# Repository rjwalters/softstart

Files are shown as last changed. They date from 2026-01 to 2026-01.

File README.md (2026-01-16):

# Generator Soft-Start

Help small portable generators (Honda EU1000i) start window air conditioners by supplementing current during motor startup.

## The Problem

A 1000W generator can run an 8000 BTU window AC (~720W) once it's running, but the compressor's startup surge (5-7× running current for 300-500ms) overwhelms the generator, causing it to bog down or trip.

## The Solution

A supercapacitor bank that:
1. Charges from the AC line during normal operation
2. Detects motor startup (current surge)
3. Injects supplemental current synchronized to the AC waveform
4. Shuts off after the motor reaches speed

## Design

```
GENERATOR ──┬──────────────────────────────────────┬── LOAD (AC Unit)
            │                                      │
            │   ┌────────────────────────────┐     │
            │   │      SUPERCAP BANK         │     │
            │   │   30 × 12F 2.7V = 81V      │     │
            └───┤                            ├─────┘
                │   Charging    Discharge    │
                │   Circuit     MOSFET       │
                │       ↑          ↑         │
                │       └────┬─────┘         │
                │            │               │
                │      ┌─────┴─────┐         │
                │      │  STM32    │         │
                │      │  MCU      │         │
                │      └───────────┘         │
                └────────────────────────────┘
                        × 2 banks
                  (positive & negative half-cycles)
```

## Specifications

| Parameter | Value |
|---|---|
| Supercapacitors | 60 × Tecate 12F 2.7V |
| Bank voltage | 81V (30 series per bank) |
| AC coverage | 32% of waveform |
| Energy delivery | ~110J in 200ms |
| Effective current | ~14A RMS |
| MCU | STM32G031 |
| **Estimated BOM** | **~$85** |

## Key Components

| Component | Part Number | Qty | Unit Cost |
|---|---|-----|---|
| Supercapacitor | Tecate TPLH-2R7/12WR10X30 | 60 | $0.91 |
| MCU | STM32G031F6P6 | 1 | $1.50 |
| MOSFET | IRFB4110 | 2 | $1.50 |
| PCB | JLCPCB 2-layer | 1 | ~$15 |

## How It Works

1. **Charging:** Supercaps charge through current-limiting resistors when AC voltage is in safe range
2. **Detection:** MCU monitors load current; spike indicates motor starting
3. **Injection:** When V_ac < 81V (near zero-crossing), MOSFET connects supercap bank
4. **PWM Control:** MCU shapes injection current to approximate sinusoid
5. **Timeout:** Assist limited to 500ms to prevent overheating

### Phase Alignment Advantage

Motor current *lags* voltage by ~70° due to inductance. This means peak current occurs near voltage zero-crossing—exactly where our injection window is. The 32% coverage captures the most critical part of the cycle.

## Project Structure

```
softstart/
├── README.md                    # This file
├── hardware/
│   ├── design_spec.md           # Detailed design specification
│   └── kicad/
│       ├── softstart.kicad_pro  # KiCad project
│       └── softstart.kicad_dru  # JLCPCB design rules
├── src/                         # Analysis scripts
├── docs/                        # Design evolution & analysis
│   ├── design_evolution.md      # How we got here
│   └── *.png                    # Analysis plots
├── requirements.txt
└── pyproject.toml
```

## Status

- [x] Design analysis complete
- [x] Component selection finalized
- [x] KiCad project initialized
- [ ] Schematic capture
- [ ] PCB layout
- [ ] Firmware development
- [ ] Prototype build
- [ ] Testing

## Safety

**This device operates at mains voltage (120VAC) and stores significant energy (81V, ~1300J). It can cause injury or death if mishandled.**

- Always discharge supercaps before servicing
- Use proper enclosure
- Include appropriate fusing
- For experimental/educational use only

## Documentation

- [Project Specification](hardware/kicad/project.kct) - Complete technical specification (kicad-tools format)
- [Design Evolution](docs/design_evolution.md) - How we explored different approaches

## License

MIT

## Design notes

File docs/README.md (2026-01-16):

# Design Documentation

This folder contains the design evolution and analysis work that led to the final supercap-only design.

## Design Evolution

See [design_evolution.md](design_evolution.md) for the complete exploration of:
- Multi-tier LiPo battery approaches (rejected)
- Hybrid supercap + electrolytic stacking (explored, rejected for complexity)
- Supercap-only with PWM (selected)

## Analysis Scripts

The `/src` folder contains Python scripts used to analyze different configurations:

| Script | Purpose |
|---|---|
| `analyze_supercap_configs.py` | Supercap-only power delivery analysis |
| `analyze_hybrid_stacking.py` | Hybrid supercap + electrolytic concept |
| `analyze_motor_startup.py` | Motor startup current requirements |
| `analyze_phase_coverage.py` | Phase alignment with inductive loads |
| `analyze_12f_design.py` | Final 12F supercap design analysis |
| `analyze_budget_design.py` | Budget constraint optimization |
| `analyze_sourcing.py` | Component sourcing options |
| `comprehensive_analysis.py` | Combined capability assessment |

## Analysis Plots

| Plot | Description |
|---|---|
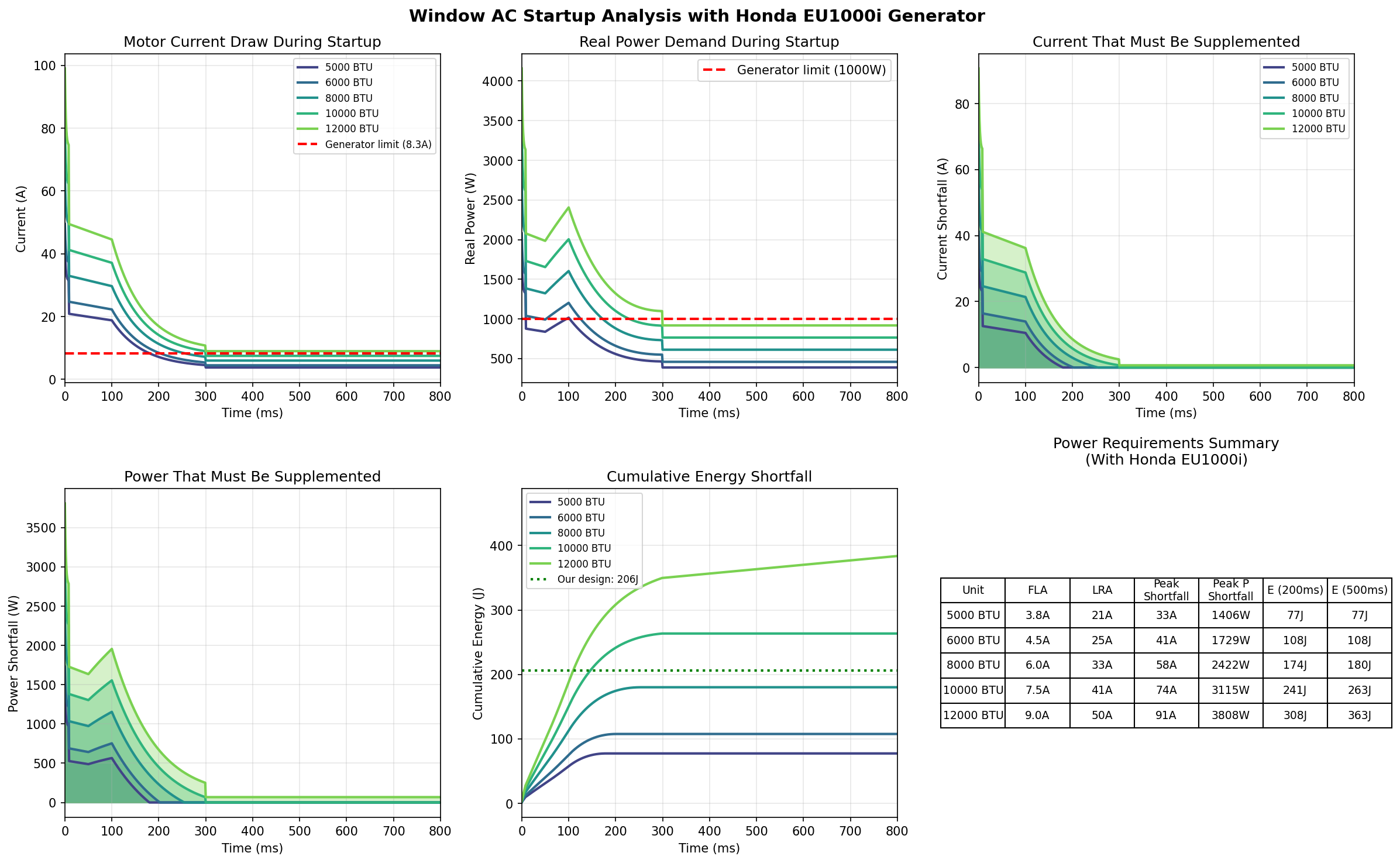
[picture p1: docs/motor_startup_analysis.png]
Motor Startup
|  | Current requirements for different AC unit sizes |
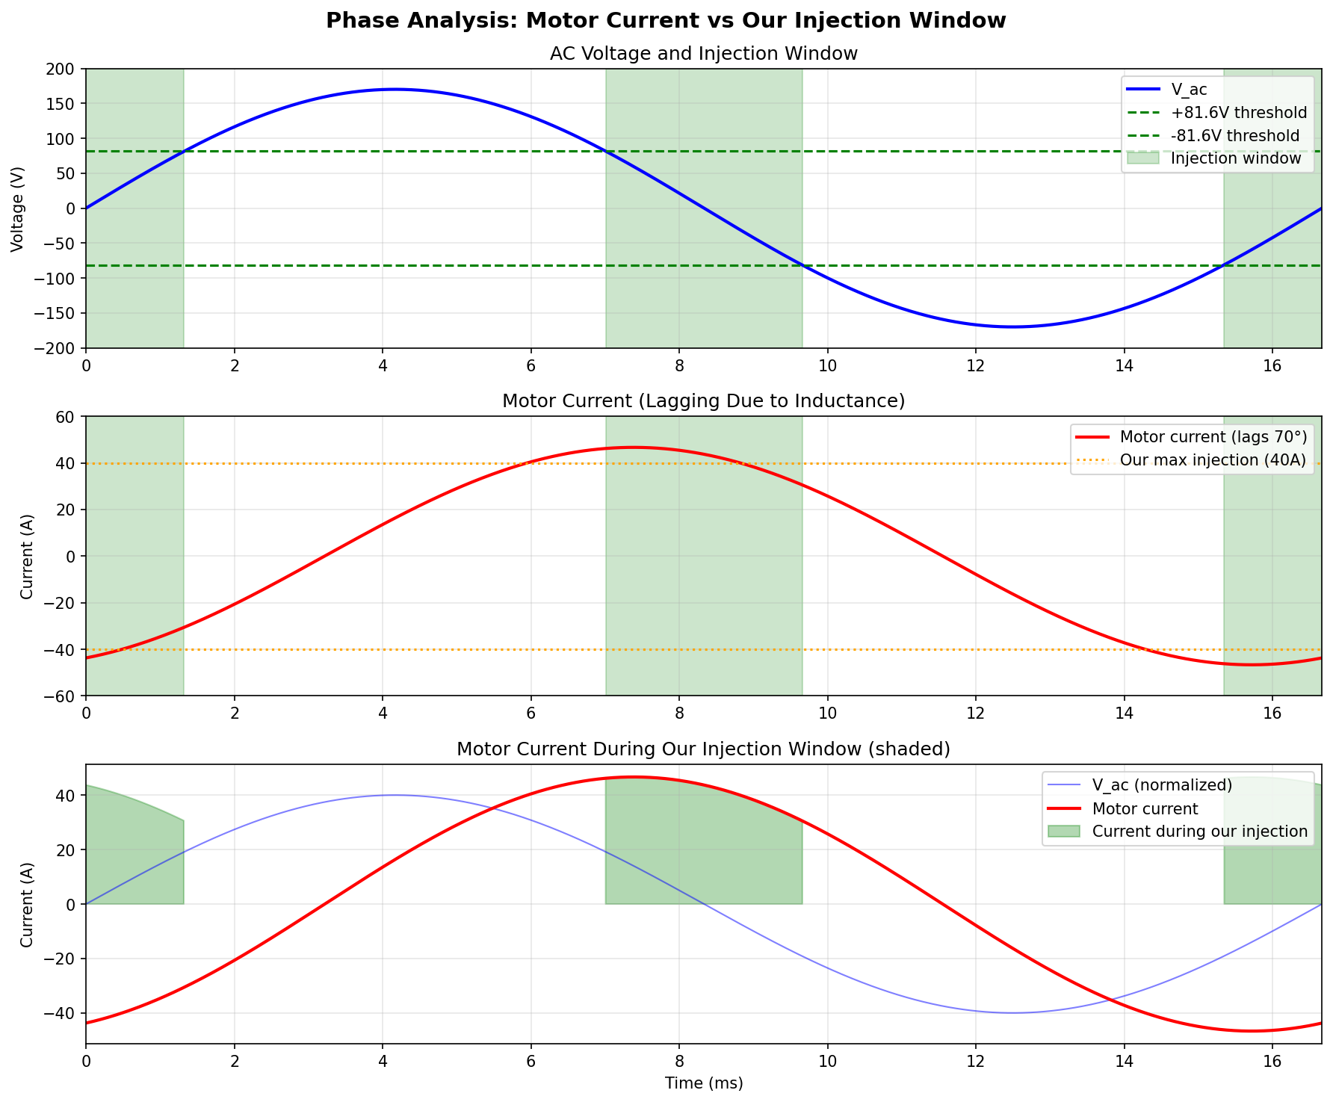
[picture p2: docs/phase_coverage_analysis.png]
Phase Coverage
|  | How injection aligns with motor current |
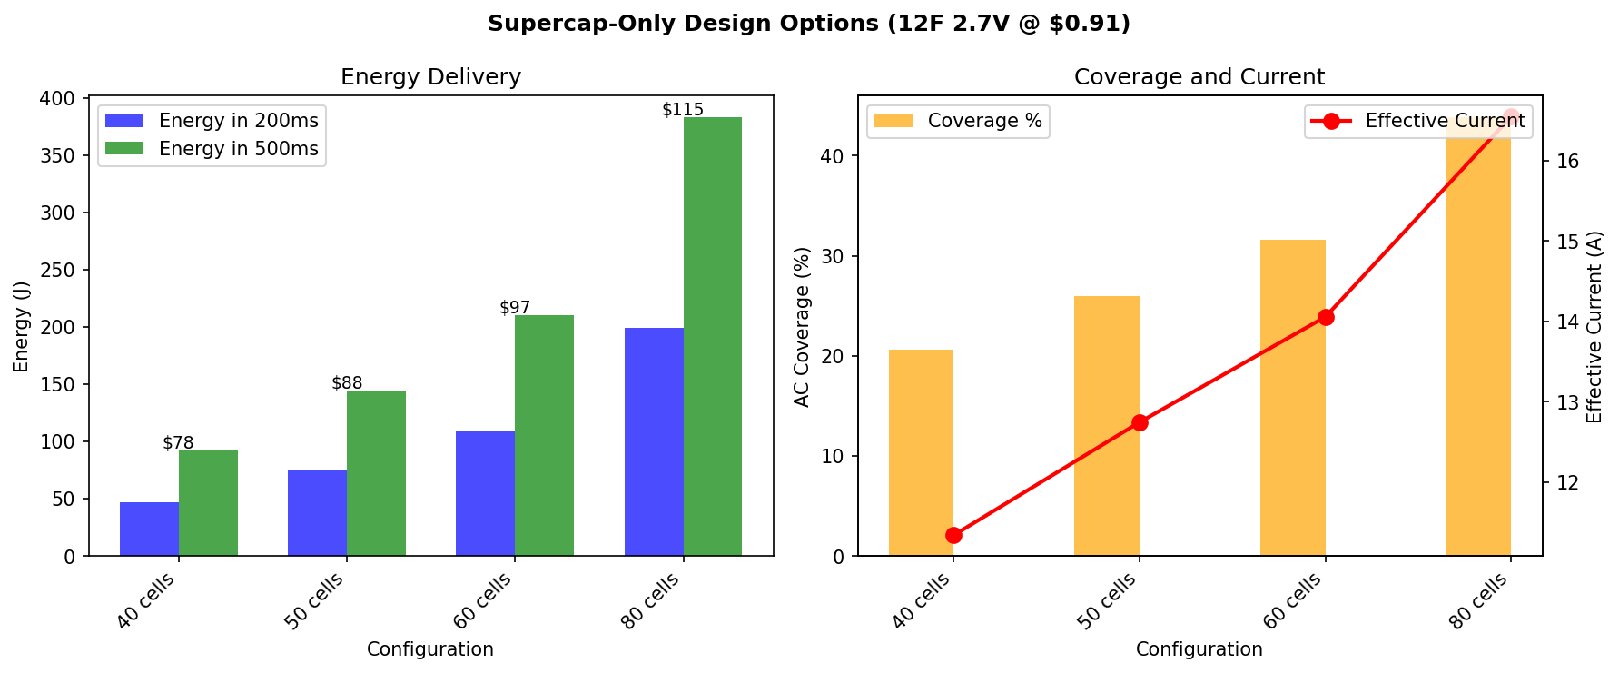
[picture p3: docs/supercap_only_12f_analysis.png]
Supercap Only
|  | Final 12F design options |
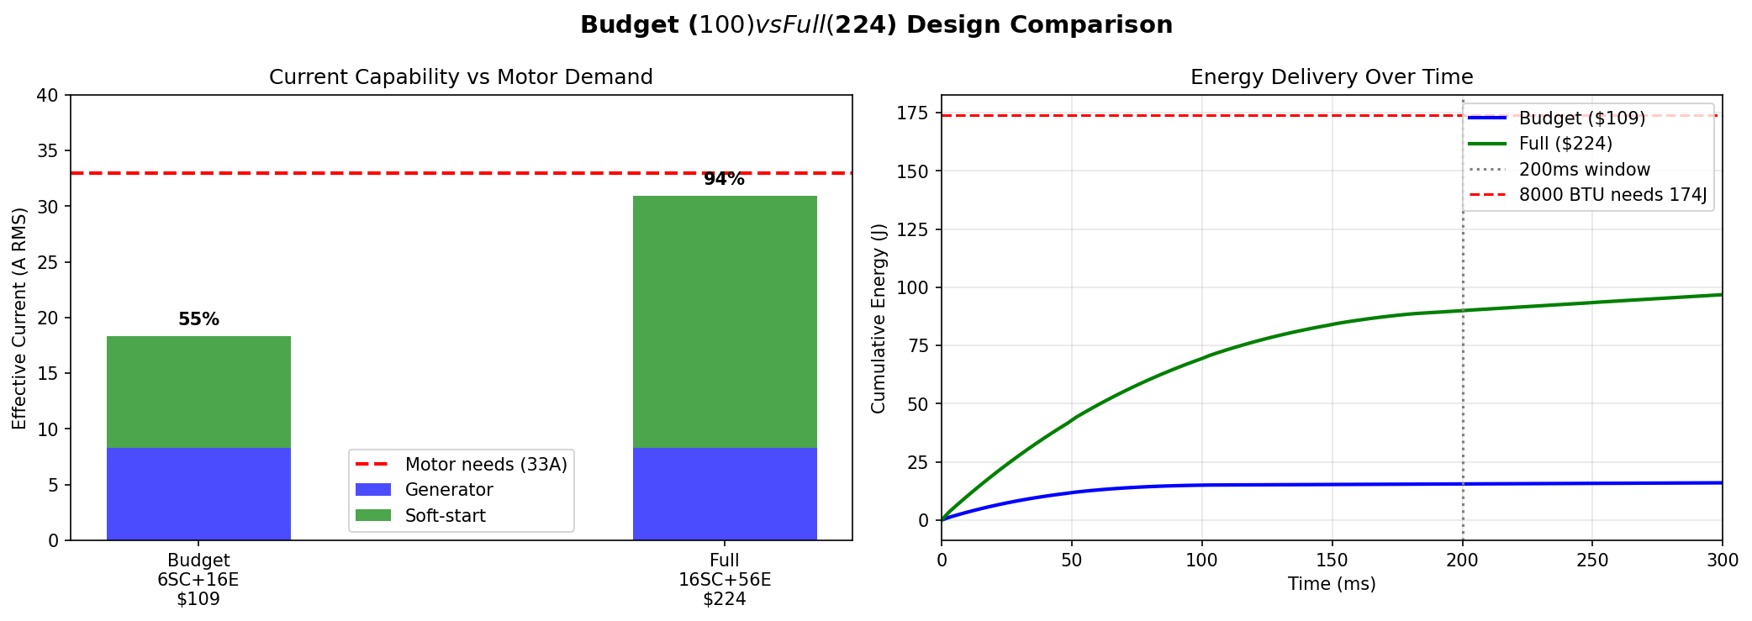
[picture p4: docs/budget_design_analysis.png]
Budget Analysis
|  | Cost vs performance trade-offs |

## Key Findings

### Motor Startup Requirements

| AC Unit | Energy Needed (200ms) | Can Start with 60-cell design? |
|---|---|---|
| 5000 BTU | ~77J | ✓ High confidence |
| 6000 BTU | ~108J | ✓ High confidence |
| 8000 BTU | ~174J | ✓ Medium confidence |
| 10000 BTU | ~241J | ? Marginal |

### Phase Alignment Advantage

Motor current lags voltage by ~70° at locked rotor (power factor ≈ 0.35). This means:
- Peak motor current occurs near voltage zero-crossing
- Our injection window (|V_ac| < 81V) includes zero-crossing
- We inject maximum current exactly when motor needs it most
- The 32% coverage captures the *critical* 32% of the AC cycle

### Why Supercap-Only Won

| Factor | Hybrid | Supercap-Only |
|---|---|---|
| Cost | $140-224 | **$85** |
| Complexity | High (8+ switches) | **Low (2 switches)** |
| Control | MCU required | Simple analog possible |
| Failure modes | Many | **Few** |
| Energy/200ms | 206J | 110J |

The hybrid delivers more energy, but the supercap-only design delivers similar *power* during the critical window at half the cost and complexity.

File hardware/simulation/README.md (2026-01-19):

# Softstart Power Supply Simulations

SPICE simulations for validating MCU power supply stability under various operating conditions.

## Overview

The softstart board uses a supercapacitor-based power assist system. The MCU power supply chain is:

```
AC Input → Bridge Rectifier (D5) → C8 (1000µF) → LM7812 → AMS1117-3.3 → STM32
```

These simulations verify that the MCU supply remains stable during:
1. **Startup** - when supercaps are discharged and drawing charging current
2. **Droop events** - when generator voltage sags and supercaps discharge
3. **Brown-out conditions** - finding minimum operating voltage

## Prerequisites

Install ngspice:

```bash
# macOS
brew install ngspice

# Ubuntu/Debian
sudo apt-get install ngspice

# Windows
# Download from http://ngspice.sourceforge.net/
```

## Running Simulations

### Run All Simulations
```bash
./run_simulations.sh all
```

### Run Individual Simulations
```bash
./run_simulations.sh startup    # Startup transient
./run_simulations.sh droop      # Droop event
./run_simulations.sh brownout   # Brown-out threshold
```

### Interactive Mode
For debugging or exploring waveforms:
```bash
./run_simulations.sh interactive startup_transient.cir
```

In ngspice interactive mode:
```
ngspice> run
ngspice> plot v(rail_3v3) v(rail_12v)
ngspice> meas tran v_min MIN v(rail_3v3)
```

## Simulation Descriptions

### 1. Startup Transient (`startup_transient.cir`)

Simulates power-on with fully discharged supercaps (worst case).

**What it tests:**
- Rectified voltage sag due to supercap charging current
- LM7812 behavior during input voltage dips
- Time to stable 3.3V rail
- MCU brown-out reset risk

**Key parameters:**
- Generator: 120V RMS, 60Hz, 2Ω internal impedance
- Supercaps: 0V initial (worst case)
- Precharge: 100Ω/220Ω resistors

**Pass criteria:**
- 3.3V rail never drops below 2.0V (BOR threshold)
- 12V rail stays above 10V

### 2. Droop Event (`droop_event.cir`)

Simulates generator voltage droop that triggers supercap assist.

**What it tests:**
- MCU supply during 25% voltage droop
- Transition behavior when supercaps start discharging
- Recovery when voltage returns to normal

**Key parameters:**
- Normal: 120V RMS
- Droop: 90V RMS (25% reduction)
- Droop duration: 200ms
- Supercaps: 60V initial (charged)

**Pass criteria:**
- No MCU reset during droop event
- 3.3V rail stays above 3.0V

### 3. Brown-out Threshold (`brownout_threshold.cir`)

Determines minimum AC input voltage for stable MCU operation.

**What it tests:**
- Slow ramp from 120V to 40V RMS
- Find exact voltage where each rail loses regulation
- Calculate safety margins

**Key measurements:**
- AC voltage where 12V rail < 11V (dropout)
- AC voltage where 3.3V rail < 3.0V (warning)
- AC voltage where 3.3V rail < 2.0V (BOR)

## Component Models

Models are in `lib/components.lib`:

| Model | Description |
|---|---|
| `LM7812` | 12V linear regulator with dropout behavior |
| `AMS1117` | 3.3V LDO with 1.1V dropout |
| `SUPERCAP_BANK_30S` | 30-series supercap bank (0.4F, 0.9Ω ESR) |
| `BRIDGE_RECT` | MB6S equivalent bridge rectifier |
| `GENERATOR` | AC source with internal impedance |
| `GENERATOR_DROOP` | AC source with controllable voltage droop |
| `STM32_LOAD` | MCU current draw and BOR detection |

## Results

Results are saved to `results/`:
- `.csv` files with waveform data
- `.log` files with measurement outputs

## Interpreting Results

### Good Results
```
PASS: 3.3V rail stayed above brownout threshold
      Minimum was: 3.15 V
PASS: No MCU reset during droop
```

### Concerning Results
```
WARNING: 3.3V rail dropped below 3.0V during droop
         Minimum: 2.85 V
```

### Failing Results
```
FAIL: 3.3V rail dropped below brownout threshold (2.0V)
      Minimum was: 1.8 V
FAIL: MCU reset during droop event!
```

## Potential Mitigations

If simulations show MCU supply instability:

1. **Increase C8** - More bulk capacitance on LM7812 input
2. **Add capacitance on 3.3V** - More local bypass (C1/C2)
3. **Supervisor IC** - Add voltage monitor with reset hold-off
4. **Separate supply** - Dedicated small transformer for MCU
5. **Pre-regulator** - Add switching pre-reg before LM7812
6. **Delay MCU startup** - Wait for supercaps to charge

## Files

```
simulation/
├── README.md                 # This file
├── run_simulations.sh        # Run script
├── lib/
│   └── components.lib        # SPICE component models
├── startup_transient.cir     # Startup test bench
├── droop_event.cir           # Droop test bench
├── brownout_threshold.cir    # Brown-out test bench
└── results/                  # Output directory
```

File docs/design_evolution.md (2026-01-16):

# Generator Power Assist (Soft Start)

## Problem Statement

Small portable generators (like the Honda EU1000i, ~1000W) struggle with inductive startup loads. When an air conditioner or refrigerator compressor starts, it draws 3-6x its running current for 1-3 seconds. This startup surge can exceed the generator's capacity, causing it to bog down or trip.

**Goal:** Supplement the generator with ~500-800W of additional power for 2-3 seconds during motor startup. The generator still provides most of the power - we just help it over the hump.

## Design Evolution

Through analysis and simulation, we explored several approaches:

1. **Multi-tier LiPo batteries** - Different voltage tiers (2S, 4S, 8S) for different parts of the AC waveform. Rejected due to BMS complexity and cycle life concerns.

2. **Supercap-only with PWM** - Simple and robust, but limited AC coverage means lower effective power delivery.

3. **Hybrid supercap + electrolytic stacking** - Best cost/performance ratio. Electrolytics provide voltage boost, supercaps provide energy storage.

## Recommended Design: Hybrid Stacking

### Core Concept

**Charge separately, discharge in series:**

```
CHARGING (separate windows):              DISCHARGING (series):

AC passes through 24V:                         Load
  → Supercaps charge to 24V                      ↑
                                           ┌─────┴─────┐
AC passes through 60V:                     │  Supercap │ 24V
  → Electrolytics charge to 60V            │   Bank    │
                                           ├───────────┤
                                           │Electrolytic│ 60V
                                           │   Bank    │
                                           └─────┬─────┘
                                              Neutral

                                    Stacked voltage: 84V
                                    Coverage: 33% of AC cycle
```

### Why Hybrid Stacking Works

| Component | Strength | Role in Hybrid |
|---|---|---|
| Supercaps | High energy density, high current | Energy storage |
| Electrolytics | High voltage rating, cheap | Voltage boost |

**Key insight:** Electrolytics are cheap per volt, supercaps are cheap per joule. Combining them optimizes both.

### Configuration Analysis

We analyzed configurations across 12-20 supercaps × 40-64 electrolytics:

**Energy delivered in first 200ms (critical motor start window):**

```
        │   40E   │   44E   │   48E   │   52E   │   56E   │   60E   │
────────┼─────────┼─────────┼─────────┼─────────┼─────────┼─────────┤
  12SC  │   129J  │   142J  │   154J  │   166J  │   178J  │   180J  │
  14SC  │   140J  │   153J  │   166J  │   179J  │   192J  │   194J  │
  16SC  │   151J  │   165J  │   178J  │   192J  │   206J  │   208J  │
  18SC  │   162J  │   177J  │   191J  │   206J  │   220J  │   223J  │
  20SC  │   174J  │   190J  │   205J  │   220J  │   235J  │   238J  │
```

**Cost ($):**

```
        │   40E   │   44E   │   48E   │   52E   │   56E   │   60E   │
────────┼─────────┼─────────┼─────────┼─────────┼─────────┼─────────┤
  12SC  │  $163   │  $172   │  $181   │  $191   │  $200   │  $209   │
  14SC  │  $175   │  $184   │  $193   │  $203   │  $212   │  $221   │
  16SC  │  $187   │  $196   │  $205   │  $215   │  $224   │  $233   │
  18SC  │  $199   │  $208   │  $217   │  $227   │  $236   │  $245   │
  20SC  │  $211   │  $220   │  $229   │  $239   │  $248   │  $257   │
```

**Sweet spot: 56 electrolytics** - Provides ~197ms boost duration, just covering the critical 200ms window. More electrolytics beyond this don't help.

### Recommended Configurations

| Goal | Config | Cost | Energy | J/$ | Notes |
|---|---|---|---|-----|---|
| **Budget** | 18SC+40E | $199 | 162J | 0.81 | Good balance |
| **Best value** | 16SC+56E | $224 | 206J | 0.92 | Optimal J/$ |
| **Maximum** | 20SC+56E | $248 | 235J | 0.95 | Best efficiency |

### Primary Recommendation: 16SC + 56E

| Parameter | Value |
|---|---|
| Supercaps | 16 total (8 per bank) |
| Electrolytics | 56 total (28 per bank) |
| **Total Cost** | **$224** |
| Supercap voltage | 21.6V (8 × 2.7V) |
| Stacked voltage | 81.6V |
| AC coverage | 32% |
| Boost duration | 197ms |
| Energy in 200ms | 206J |
| Peak power | ~1,000W |

**Cost breakdown:**
- Supercaps (100F 2.7V): 16 × $6.00 = $96
- Electrolytics (4700µF 100V): 56 × $2.28 = $128

## Target Application: Window AC Units

### Motor Startup Characteristics

Window AC compressors are challenging inductive loads:

| Unit Size | Running | FLA | LRA (5.5×) | Startup Time |
|---|---|-----|---|---|
| 5000 BTU  | 450W | 3.8A | 21A | ~200ms |
| 6000 BTU  | 540W | 4.5A | 25A | ~250ms |
| 8000 BTU  | 720W | 6.0A | 33A | ~300ms |
| 10000 BTU | 900W | 7.5A | 41A | ~350ms |
| 12000 BTU | 1080W | 9.0A | 50A | ~400ms |

**Key insight:** LRA (Locked Rotor Amps) is typically 5-7× the running current and lasts 0.5-1.5 seconds.

### Startup Current Profile

```
Current
  ↑
  │    ┌──────┐
  │    │      │ LRA (Locked Rotor)
  │    │      └──────┐
  │    │              └───────┐
  │    │                      └────────── FLA (Running)
  │    │
  └────┴──────────────────────────────────────→ Time
       0    100ms  200ms  300ms  500ms

  Phase 1: Initial surge (0-8ms) - up to 20× FLA
  Phase 2: Locked rotor (8-180ms) - ~5-7× FLA
  Phase 3: Acceleration (180-500ms) - decreasing
  Phase 4: Running - FLA steady state
```

### Phase Alignment Advantage

Our design benefits from motor inductance:

- **Motor current lags voltage by ~70°** at locked rotor (PF ≈ 0.35)
- **Peak motor current occurs near voltage zero-crossing**
- **Our injection window includes zero-crossing** (|V_ac| < 81.6V)
- **We inject maximum current exactly when motor needs it most!**

```
         V_ac                    I_motor (lagging 70°)
           │                           │
    Peak → │ ╱╲                        │    ╱╲
           │╱  ╲                       │   ╱  ╲
   ────────┼────╲─────────────────────┼──╱────╲──────
           │     ╲  ╱                  │ ╱      ╲
           │      ╲╱ ← Zero crossing   │╱        ╲ ← Peak current HERE
           │                           │

Our injection window: when |V_ac| < 81.6V (shaded region around zero crossing)
Motor peak current: at zero crossing due to 70° lag

Result: 32% AC coverage captures the most critical 32%!
```

### Capability Matrix

**Honda EU1000i + Our Hybrid Boost:**

| AC Unit | Energy Needed | Our Capacity | Margin | Can Start? |
|---|---|---|---|---|
| 5000 BTU | ~77J in 200ms | 206J | +129J | ✓✓ HIGH |
| 6000 BTU | ~108J in 200ms | 206J | +98J | ✓✓ HIGH |
| **8000 BTU** | **~174J in 200ms** | **206J** | **+32J** | **✓ MEDIUM** |
| 10000 BTU | ~241J in 200ms | 206J | -35J | ? MARGINAL |
| 12000 BTU | ~308J in 200ms | 206J | -102J | ✗ NO |

### Detailed Analysis: 8000 BTU (Target Application)

**Without soft-start:**
- Motor demands 33A LRA
- Generator can supply 8.3A max
- Shortfall: 24.7A → **voltage collapses, motor stalls**

**With our soft-start:**
- Generator provides: 8.3A
- We inject: up to 40A peak (22.6A effective RMS)
- At zero-crossing: 45.9A combined vs 43.9A needed
- Current margin: +2.0A → **motor starts successfully**

### Recommendations by Unit Size

| Target Unit | Recommended Config | Cost | Confidence |
|---|---|---|---|
| 5000-6000 BTU | Budget (18SC+40E) | $199 | HIGH |
| **8000 BTU** | **Recommended (16SC+56E)** | **$224** | **MEDIUM** |
| 10000 BTU | Maximum (20SC+56E) | $248 | LOW |
| 12000+ BTU | Use EU2200i instead | - | - |

## Why Electrolytics Need Parallel Connection

Electrolytics are paralleled for two reasons:

### 1. Discharge Duration
```
Single 4700µF at 40A:
  dV/dt = 40A / 0.0047F = 8,511 V/s
  Time to discharge 60V: 7ms (way too short!)

28 × 4700µF at 40A:
  Time to discharge: 197ms ✓
```

### 2. Current Handling
```
Single 4700µF ripple current rating: ~3A
For 40A discharge: need 40A / 3A ≈ 14 caps minimum

We use 28 per bank for duration + current margin.
```

## Circuit Architecture

```
                        POSITIVE HALF-CYCLE BANK

AC Hot ────┬─────────────────────────────────────────────────┬──── Load
           │                                                 │
           │         CHARGING MODE                           │
           │    ┌────────────────────────┐                   │
           ├────┤ SW_sc_chg              │                   │
           │    │    ↓                   │                   │
           │    │ [Supercap Bank]        │                   │
           │    │   8S × 100F = 12.5F    │                   │
           │    │   @ 21.6V              │                   │
           │    └────────┬───────────────┘                   │
           │             │                                   │
           │    ┌────────┴───────────────┐                   │
           ├────┤ SW_el_chg              │                   │
           │    │    ↓                   │                   │
           │    │ [Electrolytic Bank]    │                   │
           │    │  28 × 4700µF = 0.13F   │                   │
           │    │   @ 60V                │                   │
           │    └────────────────────────┘                   │
           │                                                 │
           │         DISCHARGE MODE (SERIES)                 │
           │    ┌────────────────────────┐                   │
           │    │      [Supercap]        │                   │
           │    │         21.6V          │                   │
           │    │           +            │                   │
           │    │     [Electrolytic]     ├───[SW_discharge]──┤
           │    │         60V            │                   │
           │    │           =            │                   │
           │    │     81.6V stacked      │                   │
           │    └────────────────────────┘                   │
           │                                                 │
Neutral ───┴─────────────────────────────────────────────────┴──── Neutral

                    (Mirror for negative half-cycle bank)
```

### Operating Modes

**Charging (Normal Operation):**
1. Monitor V_ac continuously
2. When V_ac passes through ~22V: close SW_sc_chg briefly → supercaps charge
3. When V_ac passes through ~60V: close SW_el_chg briefly → electrolytics charge
4. Banks charge independently

**Discharging (Motor Start Assist):**
1. Detect motor start (current surge or voltage dip)
2. Reconfigure switches to connect banks in series
3. Close SW_discharge with PWM control when V_ac < 81.6V
4. Inject sinusoidal current synchronized to AC phase
5. After ~200ms, electrolytics depleted → falls back to supercap-only voltage

### Switching Requirements

| Switch | Voltage Rating | Current | Qty | Notes |
|---|---|---|-----|---|
| SW_sc_chg | 50V | 20A | 2 | Supercap charging |
| SW_el_chg | 100V | 10A | 2 | Electrolytic charging |
| SW_discharge | 100V | 40A | 2 | Main power path |
| SW_series | 100V | 40A | 2 | Series connection |

## Bill of Materials

| Component | Spec | Qty | Unit | Total | Notes |
|---|---|-----|---|---|---|
| Supercapacitor | 100F 2.7V | 16 | $6.00 | $96 | 8S × 2 banks |
| Electrolytic | 4700µF 100V | 56 | $2.28 | $128 | 28 × 2 banks |
| MOSFET (charge) | 100V 20A | 4 | $1.00 | $4 | |
| MOSFET (discharge) | 100V 50A | 4 | $2.00 | $8 | IRFB4110 |
| Gate driver | IR2110 | 2 | $2.00 | $4 | |
| Current shunt | 0.01Ω 5W | 2 | $1.00 | $2 | |
| Inductor | 100µH 40A | 2 | $4.00 | $8 | PWM filtering |
| MCU | STM32F103 | 1 | $4.00 | $4 | |
| Voltage sensing | Dividers + opamp | 1 | $3.00 | $3 | |
| Connectors, fuses | Various | - | - | $15 | |
| PCB | JLCPCB 2-layer | 1 | $20.00 | $20 | ~150×200mm |
| **Total** | | | | **~$292** | |

### Alternative: Budget Build (18SC + 40E)

| Component | Qty | Cost |
|---|-----|---|
| Supercapacitors | 18 | $108 |
| Electrolytics | 40 | $91 |
| Electronics | - | ~$68 |
| **Total** | | **~$267** |

Delivers 162J in 200ms vs 206J for the recommended config.

## Specifications

| Parameter | Value | Notes |
|---|---|---|
| Input/Output | 120VAC 60Hz | Pass-through |
| Max continuous | 20A | |
| Stacked voltage | 81.6V | During boost |
| AC coverage | 32% | During boost |
| Boost duration | 197ms | Then supercap-only |
| Energy (200ms) | 206J | Critical window |
| Peak power | ~1,000W | During boost |
| Recovery time | ~60s | Full recharge |

## Comparison: Hybrid vs Supercap-Only

| Metric | Supercap Only (50SC) | Hybrid (16SC+56E) |
|---|---|---|
| Cost | $300 | $224 |
| Voltage | 67.5V | 81.6V |
| Coverage | 26% | 32% |
| Energy/200ms | ~85J | 206J |
| Peak power | ~700W | ~1,000W |
| Complexity | Simple | Moderate |

**Hybrid delivers 2.4× more energy at 25% lower cost.**

## Firmware Architecture

### State Machine

```
                      ┌─────────┐
                      │  INIT   │
                      └────┬────┘
                           │
                           ▼
         ┌─────────────────────────────────┐
         │          CHARGING               │
         │  - Monitor V_ac                 │
         │  - Charge supercaps at ~22V     │
         │  - Charge electrolytics at ~60V │
         └───────────────┬─────────────────┘
                         │ Both banks charged
                         ▼
                    ┌─────────┐
         ┌─────────│  READY  │←────────────┐
         │         └────┬────┘             │
         │              │ Motor start      │ Assist complete
         │              │ detected         │
         │              ▼                  │
         │    ┌──────────────────┐         │
         │    │     BOOST        │         │
         │    │  Series discharge│─────────┤
         │    │  @ 81.6V         │         │
         │    └────────┬─────────┘         │
         │             │ Electrolytics     │
         │             │ depleted          │
         │             ▼                   │
         │    ┌──────────────────┐         │
         └───→│   SUSTAIN        │─────────┘
              │  Supercap-only   │
              │  @ 21.6V         │
              └──────────────────┘
```

### Control Loop (20kHz)

```c
void control_loop(void) {
    float v_ac = sample_voltage();
    float i_load = sample_current();

    switch (state) {
        case CHARGING:
            // Charge supercaps when V_ac ~ 22V
            if (fabs(v_ac - 22.0) < 3.0 && v_supercap < 21.0) {
                enable_supercap_charge();
            }
            // Charge electrolytics when V_ac ~ 60V
            if (fabs(v_ac - 60.0) < 5.0 && v_elec < 58.0) {
                enable_electrolytic_charge();
            }
            // Check if ready
            if (v_supercap > 20.0 && v_elec > 55.0) {
                state = READY;
            }
            break;

        case READY:
            // Detect motor start
            if (i_load > I_THRESHOLD || detect_voltage_dip()) {
                configure_series_discharge();
                state = BOOST;
                boost_timer = 0;
            }
            break;

        case BOOST:
            // PWM discharge at stacked voltage
            if (fabs(v_ac) < v_supercap + v_elec) {
                float i_target = I_MAX * fabs(sin(phase));
                pwm_current_control(i_target);
            }
            // Check if electrolytics depleted
            if (v_elec < 10.0 || boost_timer > 300) {
                configure_supercap_only();
                state = SUSTAIN;
            }
            break;

        case SUSTAIN:
            // Continue with supercap-only
            if (fabs(v_ac) < v_supercap) {
                float i_target = I_MAX * fabs(sin(phase));
                pwm_current_control(i_target);
            }
            // Return to charging when assist complete
            if (assist_complete()) {
                state = CHARGING;
            }
            break;
    }
}
```

## Safety Features

### Hardware
- Input fuse: 25A fast-blow
- MOSFETs derated 2× for voltage and current
- Thermal shutdown via NTC on heatsink
- Current limiting via series inductor

### Firmware
- Overcurrent shutdown (>50A)
- Overvoltage lockout (supercap >24V, electrolytic >65V)
- Undervoltage lockout (supercap <15V)
- Assist timeout (5 second max)
- Watchdog timer

### Operational
- No backfeed capability (current source, not voltage source)
- Fail-safe: all switches open on fault
- Soft-start charging to limit inrush

## Development Roadmap

### Phase 1: Simulation ✓
- [x] Supercap-only analysis
- [x] Hybrid stacking concept
- [x] Cost optimization matrix
- [x] Energy delivery modeling
- [x] Motor startup requirements analysis
- [x] Phase alignment analysis (inductive load)
- [x] Comprehensive capability assessment

### Phase 2: Hardware Design
- [ ] Detailed schematic (KiCad)
- [ ] PCB layout with high-current paths
- [ ] Thermal analysis
- [ ] Component sourcing

### Phase 3: Firmware
- [ ] Zero-crossing detection
- [ ] Charge management
- [ ] Series/parallel reconfiguration
- [ ] PWM current control
- [ ] Protection features

### Phase 4: Prototype & Test
- [ ] PCB fabrication
- [ ] Assembly
- [ ] Bench testing
- [ ] Motor load testing

## Files

```
softstart/
├── README.md                           # This file
├── src/
│   ├── analyze_supercap_configs.py     # Supercap-only analysis
│   ├── analyze_hybrid_stacking.py      # Hybrid concept analysis
│   ├── optimize_minimal_hybrid.py      # Cost optimization
│   ├── analyze_motor_startup.py        # Motor startup requirements
│   ├── analyze_phase_coverage.py       # Phase alignment analysis
│   └── comprehensive_analysis.py       # Full capability analysis
├── supercap_analysis.png               # Supercap-only plots
├── hybrid_stacking_analysis.png        # Hybrid comparison plots
├── minimal_hybrid_optimization.png     # Cost optimization plots
├── motor_startup_analysis.png          # Motor startup plots
├── phase_coverage_analysis.png         # Phase alignment plots
└── comprehensive_analysis.png          # Capability matrix plots
```

## References

- Honda EU1000i specifications
- Maxwell/UCAP supercapacitor datasheets (100F 2.7V)
- Nichicon/Panasonic electrolytic capacitor datasheets
- IR2110 gate driver application notes
- Motor inrush current characteristics
- [EcoFlow battery/inverter matching guide](https://www.ecoflow.com/us/blog/battery-start-air-conditioner-guide)
- [HVAC School - Start capacitor and inrush](http://www.hvacrschool.com/start-capacitor-inrush-facts-myths-part-4/)
- [Ametherm - AC motor inrush current](https://www.ametherm.com/blog/inrush-current/ac-motor-inrush/)

## License

TBD

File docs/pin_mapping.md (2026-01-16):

# STM32G031F6P6 Pin Mapping

## Signal Assignments

| Pin | Port | Function | Signal | Description |
|-----|---|---|---|---|
| 7 | PA0 | GPIO/EXTI | ZC_OUT | Zero-crossing detector input |
| 8 | PA1 | ADC_IN1 | V_AC_SENSE | AC voltage sensing |
| 9 | PA2 | ADC_IN2 | V_SC_POS | Positive supercap bank voltage |
| 10 | PA3 | ADC_IN3 | V_SC_NEG | Negative supercap bank voltage |
| 11 | PA4 | ADC_IN4 | I_SENSE | Load current sensing |
| 12 | PA5 | GPIO | CHG_EN_POS | Positive bank charge enable |
| 13 | PA6 | TIM3_CH1 | PWM_POS | Positive half-cycle discharge PWM |
| 14 | PA7 | TIM3_CH2 | PWM_NEG | Negative half-cycle discharge PWM |
| 15 | PA8 | GPIO | CHG_EN_NEG | Negative bank charge enable |
| 16 | PA11 | GPIO | LED_STATUS | Status LED output |
| 18 | PA13 | SWD | SWDIO | Debug data |
| 19 | PA14 | SWD | SWCLK | Debug clock |
| 6 | PF2 | NRST | NRST | Reset (directly to header) |

## Power Pins

| Pin | Function | Connection |
|-----|---|---|
| 4 | VDD | 3.3V rail |
| 5 | VSS | Ground |

## Unused Pins

| Pin | Port | Notes |
|-----|---|---|
| 1 | PB7/PB8 | Available for expansion |
| 2 | PB9/PC14 | Available for expansion |
| 3 | PC15 | Available for expansion |
| 17 | PA10/PA12 | Available for expansion |
| 20 | PB3-PB6 | Available for expansion |

## ADC Configuration

- ADC clock: 16 MHz (from PCLK/4)
- Resolution: 12-bit
- Sampling time: 12.5 cycles (for ~1 MHz sample rate)
- Channels: IN1, IN2, IN3, IN4 (scan mode)

## Timer Configuration

- TIM3: PWM generation for discharge MOSFETs
  - CH1 (PA6): PWM_POS
  - CH2 (PA7): PWM_NEG
  - Frequency: 20 kHz
  - Resolution: 10-bit (0-1000 duty)

## Interrupt Sources

- EXTI0 (PA0): Zero-crossing rising edge
- TIM3: PWM period interrupt for ADC trigger
- Systick: 1 kHz for state machine timing

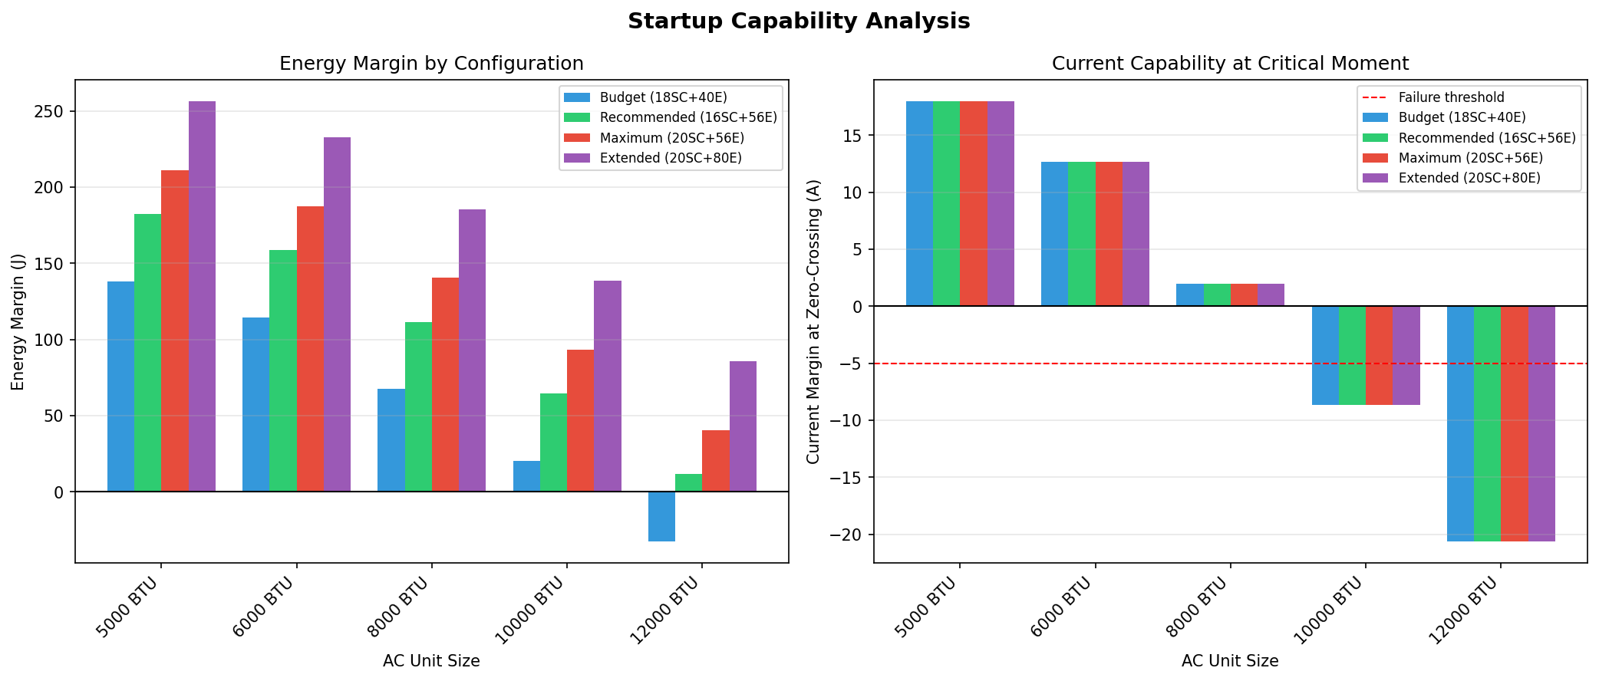
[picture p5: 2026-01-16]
docs/comprehensive_analysis.png

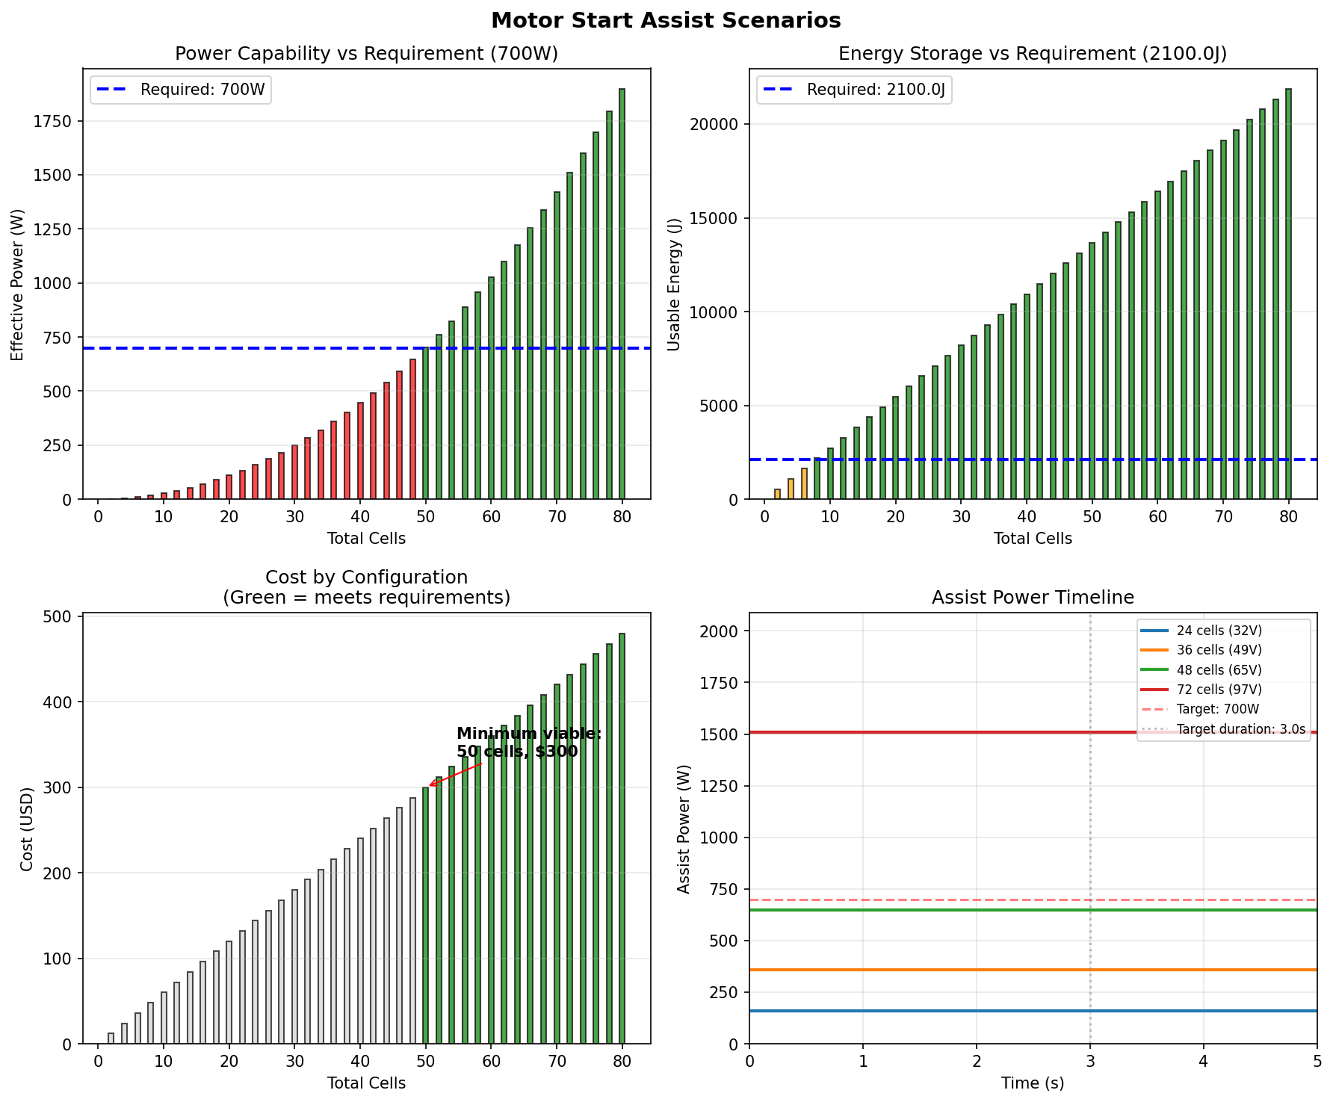
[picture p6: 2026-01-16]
docs/motor_start_scenario.png

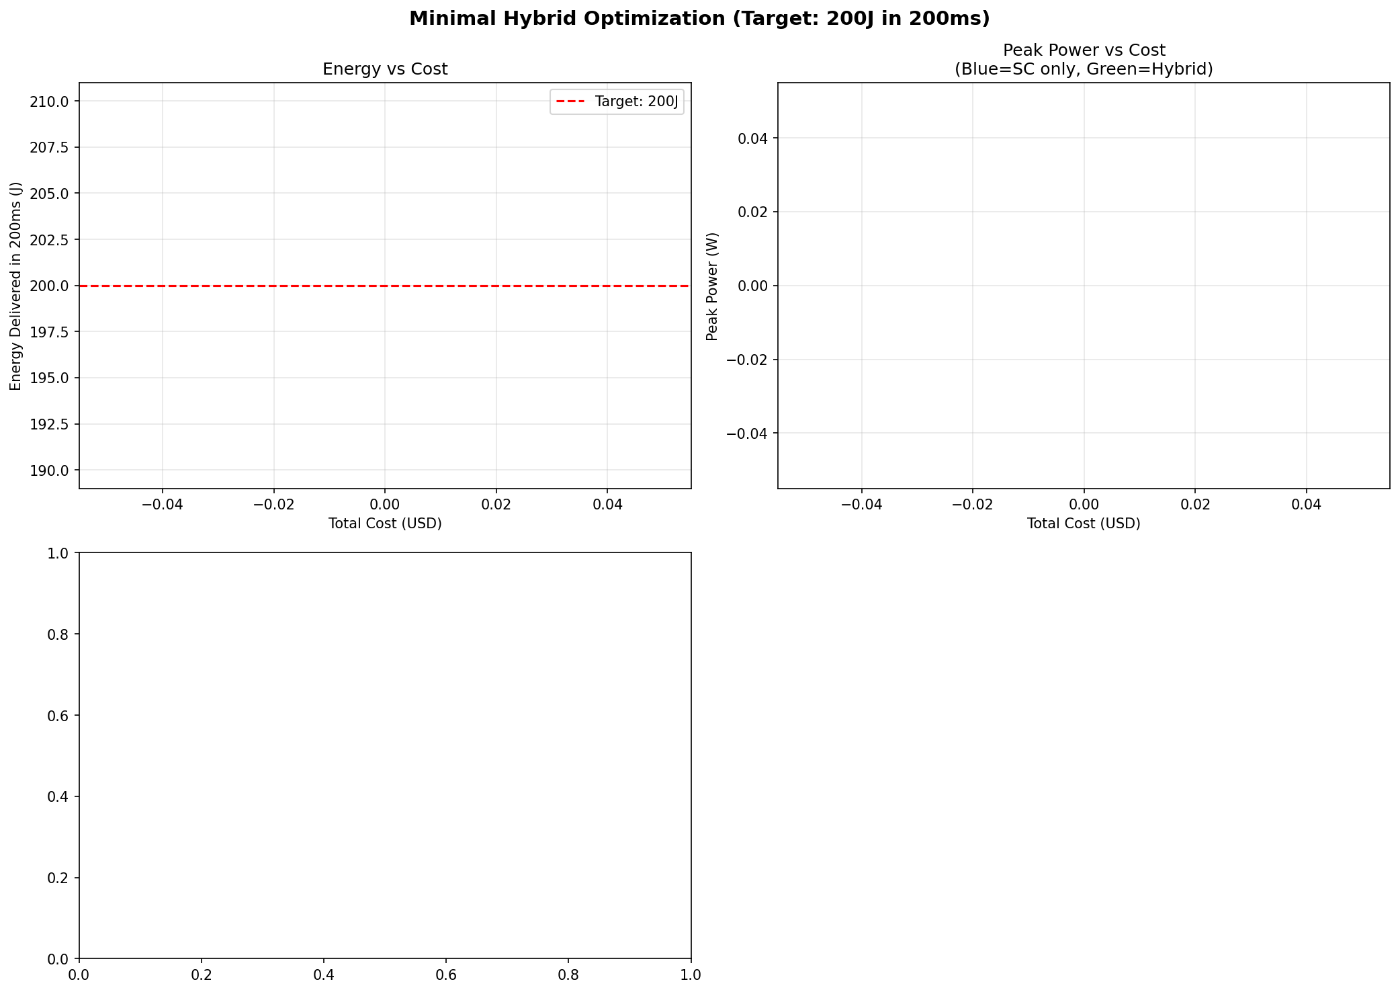
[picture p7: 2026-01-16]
docs/minimal_hybrid_optimization.png

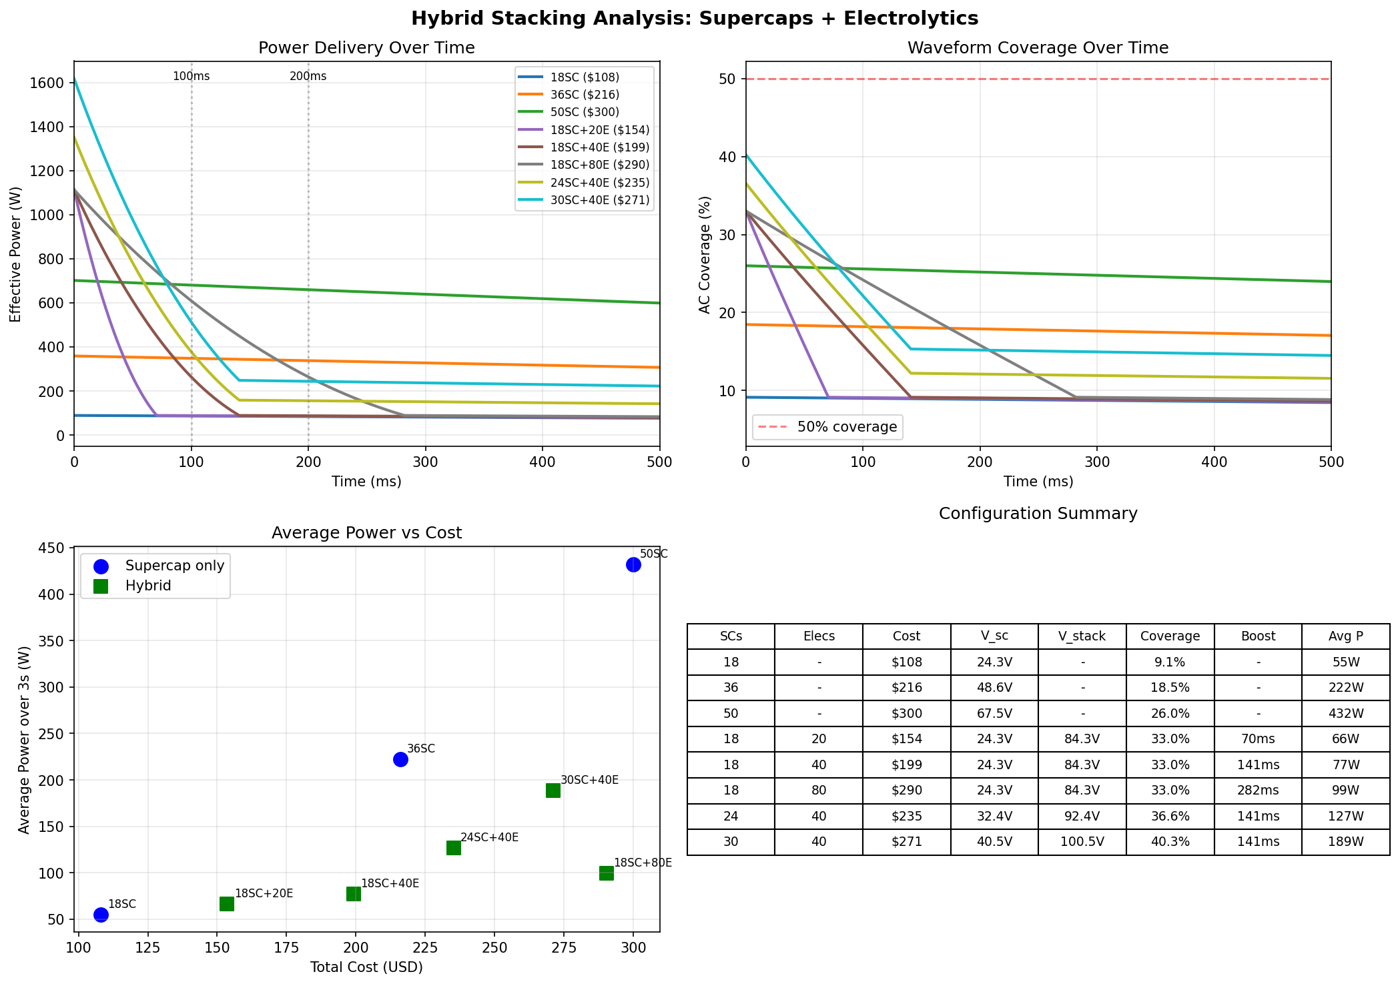
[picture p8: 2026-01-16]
docs/hybrid_stacking_analysis.png

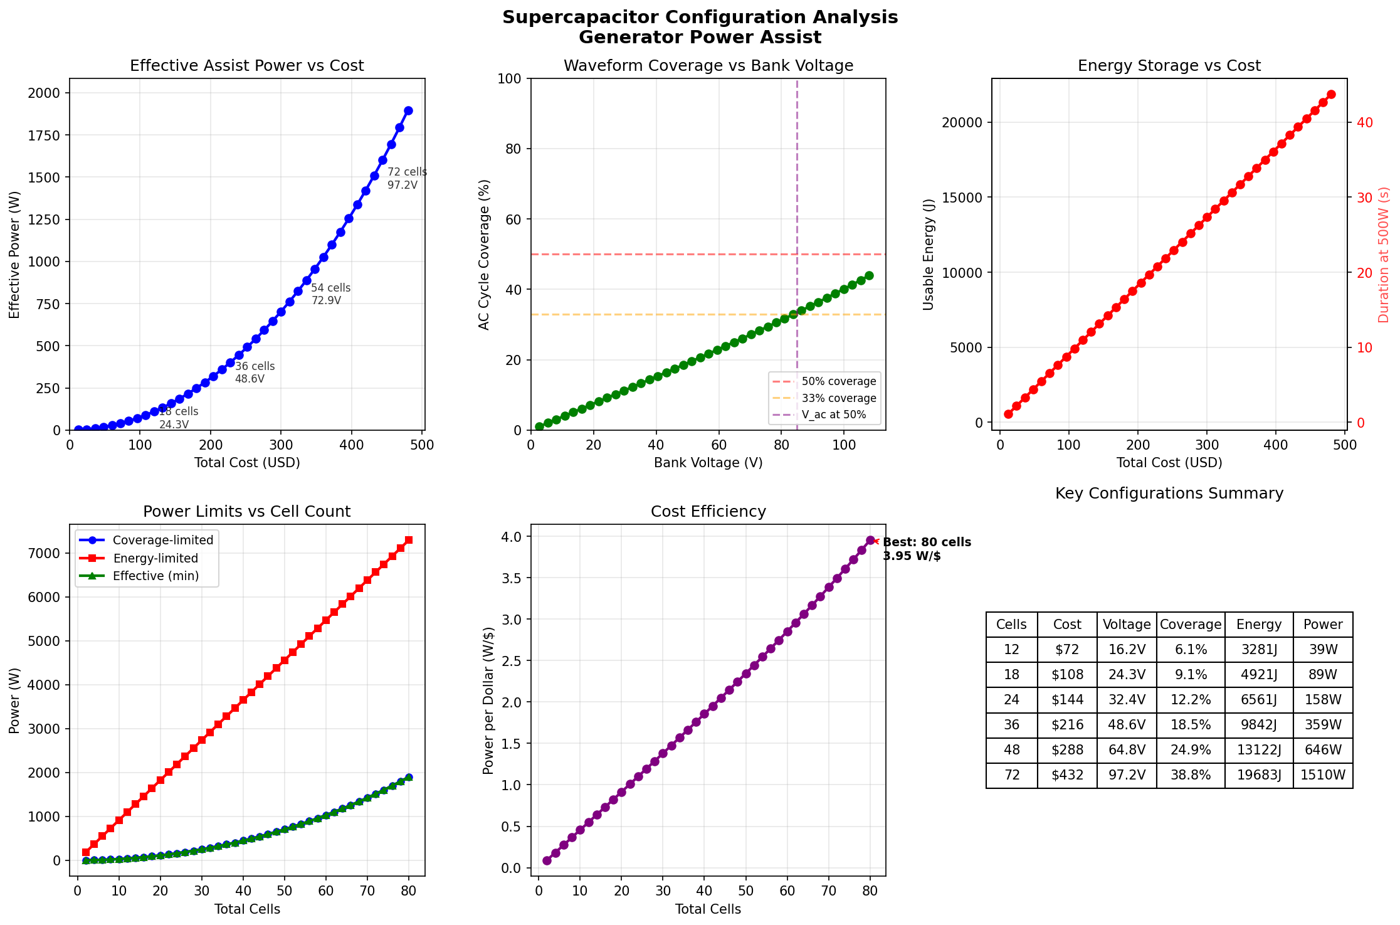
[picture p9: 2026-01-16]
docs/supercap_analysis.png

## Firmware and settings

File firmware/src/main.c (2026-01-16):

/*
 * Generator Soft-Start Firmware
 * Main Application
 *
 * Provides supplemental current during AC motor startup using
 * supercapacitor banks, synchronized to AC line phase.
 */

#include "softstart.h"

/* Global state variables */
volatile softstart_state_t g_state = STATE_INIT;
volatile fault_code_t g_fault = FAULT_NONE;
volatile uint32_t g_systick_ms = 0;
volatile bool g_zc_flag = false;
volatile bool g_zc_polarity = false;
volatile adc_readings_t g_adc = {0};

/* Local variables */
static uint32_t state_entry_time = 0;
static uint16_t boost_duty = 0;

/*
 * System Initialization
 */
void system_init(void) {
    /* Enable HSI (16 MHz internal oscillator) */
    RCC->CR |= RCC_CR_HSION;
    while (!(RCC->CR & RCC_CR_HSIRDY));

    /* Configure flash wait states for 16 MHz */
    /* (0 wait states for up to 24 MHz) */

    /* Enable GPIO clocks */
    RCC->IOPENR |= RCC_IOPENR_GPIOAEN | RCC_IOPENR_GPIOBEN;

    /* Enable peripheral clocks */
    RCC->APBENR1 |= RCC_APBENR1_TIM3EN;
    RCC->APBENR2 |= RCC_APBENR2_ADCEN | RCC_APBENR2_SYSCFGEN;
}

/*
 * GPIO Initialization
 */
void gpio_init(void) {
    /* PA0: Input (zero-crossing) with pull-down */
    GPIOA->MODER &= ~(3UL << (PIN_ZC_OUT * 2));      /* Input mode */
    GPIOA->PUPDR |= (2UL << (PIN_ZC_OUT * 2));      /* Pull-down */

    /* PA1-PA4: Analog inputs (ADC) */
    GPIOA->MODER |= (3UL << (PIN_V_AC_SENSE * 2));
    GPIOA->MODER |= (3UL << (PIN_V_SC_POS * 2));
    GPIOA->MODER |= (3UL << (PIN_V_SC_NEG * 2));
    GPIOA->MODER |= (3UL << (PIN_I_SENSE * 2));

    /* PA5, PA8: Output (charge enable) - start disabled */
    GPIOA->MODER &= ~(3UL << (PIN_CHG_EN_POS * 2));
    GPIOA->MODER |= (1UL << (PIN_CHG_EN_POS * 2));  /* Output */
    GPIOA->BSRR = (1UL << (PIN_CHG_EN_POS + 16));   /* Set low */

    GPIOA->MODER &= ~(3UL << (PIN_CHG_EN_NEG * 2));
    GPIOA->MODER |= (1UL << (PIN_CHG_EN_NEG * 2));  /* Output */
    GPIOA->BSRR = (1UL << (PIN_CHG_EN_NEG + 16));   /* Set low */

    /* PA6, PA7: Alternate function (TIM3 CH1/CH2 PWM) */
    GPIOA->MODER &= ~(3UL << (PIN_PWM_POS * 2));
    GPIOA->MODER |= (2UL << (PIN_PWM_POS * 2));     /* Alt function */
    GPIOA->AFRL &= ~(0xFUL << (PIN_PWM_POS * 4));
    GPIOA->AFRL |= (1UL << (PIN_PWM_POS * 4));      /* AF1 = TIM3 */

    GPIOA->MODER &= ~(3UL << (PIN_PWM_NEG * 2));
    GPIOA->MODER |= (2UL << (PIN_PWM_NEG * 2));     /* Alt function */
    GPIOA->AFRL &= ~(0xFUL << (PIN_PWM_NEG * 4));
    GPIOA->AFRL |= (1UL << (PIN_PWM_NEG * 4));      /* AF1 = TIM3 */

    /* PA11: Output (LED) - start off */
    GPIOA->MODER &= ~(3UL << (PIN_LED_STATUS * 2));
    GPIOA->MODER |= (1UL << (PIN_LED_STATUS * 2));  /* Output */
    GPIOA->BSRR = (1UL << (PIN_LED_STATUS + 16));   /* Set low */
}

/*
 * ADC Initialization
 */
void adc_init(void) {
    /* Ensure ADC is disabled */
    if (ADC1->CR & ADC_CR_ADEN) {
        ADC1->CR |= ADC_CR_ADDIS;
        while (ADC1->CR & ADC_CR_ADEN);
    }

    /* Configure ADC clock (PCLK/4 = 4 MHz) */
    ADC1->CFGR2 = (2UL << 30);  /* PCLK/4 */

    /* Calibrate ADC */
    ADC1->CR |= ADC_CR_ADCAL;
    while (ADC1->CR & ADC_CR_ADCAL);

    /* Configure sampling time (12.5 cycles for all channels) */
    ADC1->SMPR = (2UL << 0);  /* 12.5 cycles */

    /* Enable ADC voltage regulator (if present) */
    /* Wait for stabilization */
    for (volatile int i = 0; i < 1000; i++);

    /* Enable ADC */
    ADC1->ISR |= ADC_ISR_ADRDY;  /* Clear ready flag */
    ADC1->CR |= ADC_CR_ADEN;
    while (!(ADC1->ISR & ADC_ISR_ADRDY));

    /* Configure for single conversion, right-aligned */
    ADC1->CFGR1 = 0;
}

/*
 * Timer Initialization (PWM)
 */
void timer_init(void) {
    /* TIM3: 20 kHz PWM on CH1 and CH2 */

    /* Set prescaler and period for 20 kHz */
    TIM3->PSC = 0;                      /* No prescaler */
    TIM3->ARR = PWM_PERIOD - 1;         /* Auto-reload value */

    /* Configure CH1 and CH2 for PWM mode 1 */
    TIM3->CCMR1 = TIM_CCMR1_OC1M_PWM1 | TIM_CCMR1_OC1PE |
                  TIM_CCMR1_OC2M_PWM1 | TIM_CCMR1_OC2PE;

    /* Set initial duty cycle to 0 */
    TIM3->CCR1 = 0;
    TIM3->CCR2 = 0;

    /* Enable CH1 and CH2 outputs */
    TIM3->CCER = TIM_CCER_CC1E | TIM_CCER_CC2E;

    /* Enable auto-reload preload */
    TIM3->CR1 = TIM_CR1_ARPE;

    /* Generate update event to load registers */
    TIM3->EGR = TIM_EGR_UG;

    /* Enable timer */
    TIM3->CR1 |= TIM_CR1_CEN;
}

/*
 * EXTI Initialization (Zero-crossing interrupt)
 */
void exti_init(void) {
    /* Configure EXTI line 0 for PA0 */
    /* On STM32G0, EXTICR is in EXTI peripheral, not SYSCFG */
    EXTI->EXTICR[0] = 0;  /* PA0 as EXTI0 source */

    /* Enable rising edge trigger for EXTI0 */
    EXTI->RTSR1 |= (1UL << 0);
    EXTI->FTSR1 &= ~(1UL << 0);

    /* Enable EXTI0 interrupt mask */
    EXTI->IMR1 |= (1UL << 0);

    /* Enable EXTI0_1 interrupt in NVIC */
    *NVIC_ISER |= (1UL << EXTI0_1_IRQn);
}

/*
 * SysTick Initialization (1ms tick)
 */
void systick_init(void) {
    *SYSTICK_LOAD = (SYSCLK_FREQ / 1000) - 1;  /* 1ms period */
    *SYSTICK_VAL = 0;
    *SYSTICK_CTRL = SYSTICK_CTRL_ENABLE | SYSTICK_CTRL_TICKINT |
                    SYSTICK_CTRL_CLKSOURCE;
}

/*
 * SysTick Interrupt Handler
 */
void SysTick_Handler(void) {
    g_systick_ms++;
}

/*
 * EXTI0_1 Interrupt Handler (Zero-crossing)
 */
void EXTI0_1_IRQHandler(void) {
    if (EXTI->RPR1 & (1UL << 0)) {
        /* Rising edge detected */
        EXTI->RPR1 = (1UL << 0);  /* Clear pending flag */

        g_zc_flag = true;
        g_zc_polarity = !g_zc_polarity;  /* Toggle polarity */
    }
}

/*
 * Millisecond counter
 */
uint32_t millis(void) {
    return g_systick_ms;
}

/*
 * Delay in milliseconds
 */
void delay_ms(uint32_t ms) {
    uint32_t start = g_systick_ms;
    while ((g_systick_ms - start) < ms);
}

/*
 * ADC single channel read
 */
uint16_t adc_read_channel(uint8_t channel) {
    /* Select channel */
    ADC1->CHSELR = (1UL << channel);

    /* Start conversion */
    ADC1->CR |= ADC_CR_ADSTART;

    /* Wait for conversion complete */
    while (!(ADC1->ISR & ADC_ISR_EOC));

    /* Return result */
    return (uint16_t)ADC1->DR;
}

/*
 * Read all ADC channels
 */
void adc_read_all(adc_readings_t *readings) {
    readings->v_ac = adc_read_channel(ADC_CH_V_AC);
    readings->v_sc_pos = adc_read_channel(ADC_CH_V_SC_POS);
    readings->v_sc_neg = adc_read_channel(ADC_CH_V_SC_NEG);
    readings->i_load = adc_read_channel(ADC_CH_I_SENSE);
}

/*
 * Set positive bank PWM duty cycle
 */
void pwm_set_pos(uint16_t duty) {
    if (duty > PWM_PERIOD) duty = PWM_PERIOD;
    TIM3->CCR1 = duty;
}

/*
 * Set negative bank PWM duty cycle
 */
void pwm_set_neg(uint16_t duty) {
    if (duty > PWM_PERIOD) duty = PWM_PERIOD;
    TIM3->CCR2 = duty;
}

/*
 * Disable all PWM outputs
 */
void pwm_disable(void) {
    TIM3->CCR1 = 0;
    TIM3->CCR2 = 0;
}

/*
 * Enable/disable positive bank charging
 */
void charge_enable_pos(bool enable) {
    if (enable) {
        GPIOA->BSRR = (1UL << PIN_CHG_EN_POS);
    } else {
        GPIOA->BSRR = (1UL << (PIN_CHG_EN_POS + 16));
    }
}

/*
 * Enable/disable negative bank charging
 */
void charge_enable_neg(bool enable) {
    if (enable) {
        GPIOA->BSRR = (1UL << PIN_CHG_EN_NEG);
    } else {
        GPIOA->BSRR = (1UL << (PIN_CHG_EN_NEG + 16));
    }
}

/*
 * Set LED state
 */
void led_set(bool on) {
    if (on) {
        GPIOA->BSRR = (1UL << PIN_LED_STATUS);
    } else {
        GPIOA->BSRR = (1UL << (PIN_LED_STATUS + 16));
    }
}

/*
 * Toggle LED
 */
void led_toggle(void) {
    GPIOA->ODR ^= (1UL << PIN_LED_STATUS);
}

/*
 * Convert ADC reading to voltage in mV
 */
uint32_t adc_to_voltage_mv(uint16_t adc_val, uint32_t ratio) {
    /* voltage = adc * vref / 4096 * ratio / 100 */
    uint32_t mv = ((uint32_t)adc_val * ADC_VREF_MV * ratio) / (ADC_MAX * 100);
    return mv;
}

/*
 * Convert ADC reading to current in mA
 */
uint32_t adc_to_current_ma(uint16_t adc_val) {
    /* current = adc * 1000 / 310 */
    return ((uint32_t)adc_val * 1000) / I_SENSE_COUNTS_PER_A;
}

/*
 * Enter fault state
 */
void enter_fault(fault_code_t code) {
    g_fault = code;
    g_state = STATE_FAULT;

    /* Disable all outputs */
    pwm_disable();
    charge_enable_pos(false);
    charge_enable_neg(false);
}

/*
 * Check if motor startup detected
 * Returns true if current draw indicates motor starting
 */
bool check_motor_start(void) {
    /* Motor startup indicated by current spike above threshold */
    uint32_t current_ma = adc_to_current_ma(g_adc.i_load);
    return (current_ma > 5000);  /* > 5A indicates startup */
}

/*
 * Check if supercaps are fully charged
 */
static bool supercaps_charged(void) {
    uint32_t v_pos = adc_to_voltage_mv(g_adc.v_sc_pos, V_SC_RATIO);
    uint32_t v_neg = adc_to_voltage_mv(g_adc.v_sc_neg, V_SC_RATIO);

    /* Consider charged if both banks > 75V */
    return (v_pos > 75000 && v_neg > 75000);
}

/*
 * Check safety limits
 */
static bool check_safety(void) {
    uint32_t v_ac = adc_to_voltage_mv(g_adc.v_ac, V_AC_RATIO);
    uint32_t v_pos = adc_to_voltage_mv(g_adc.v_sc_pos, V_SC_RATIO);
    uint32_t v_neg = adc_to_voltage_mv(g_adc.v_sc_neg, V_SC_RATIO);
    uint32_t i_load = adc_to_current_ma(g_adc.i_load);

    /* Check AC voltage range */
    if (v_ac < 90000) {  /* Below ~90V peak */
        enter_fault(FAULT_UNDERVOLTAGE);
        return false;
    }
    if (v_ac > 200000) {  /* Above ~200V peak */
        enter_fault(FAULT_OVERVOLTAGE);
        return false;
    }

    /* Check supercap overvoltage */
    if (v_pos > V_SC_MAX_MV || v_neg > V_SC_MAX_MV) {
        enter_fault(FAULT_SUPERCAP_OV);
        return false;
    }

    /* Check overcurrent */
    if (i_load > I_LOAD_MAX_MA) {
        enter_fault(FAULT_OVERCURRENT);
        return false;
    }

    return true;
}

/*
 * Main state machine
 */
void state_machine_run(void) {
    uint32_t now = millis();

    /* Read ADC values */
    adc_read_all((adc_readings_t *)&g_adc);

    /* Check safety limits (except in fault state) */
    if (g_state != STATE_FAULT && g_state != STATE_INIT) {
        if (!check_safety()) {
            return;
        }
    }

    switch (g_state) {
        case STATE_INIT:
            /* Initialization complete, go to charging */
            g_state = STATE_CHARGING;
            state_entry_time = now;
            led_set(false);
            break;

        case STATE_CHARGING:
            /* Enable charging for both banks */
            charge_enable_pos(true);
            charge_enable_neg(true);

            /* Blink LED slowly while charging */
            if ((now / 500) & 1) {
                led_set(true);
            } else {
                led_set(false);
            }

            /* Check if fully charged */
            if (supercaps_charged()) {
                g_state = STATE_READY;
                state_entry_time = now;
            }

            /* Timeout check */
            if ((now - state_entry_time) > CHARGE_TIMEOUT_MS) {
                enter_fault(FAULT_TIMEOUT);
            }
            break;

        case STATE_READY:
            /* Keep charging to maintain voltage */
            charge_enable_pos(true);
            charge_enable_neg(true);

            /* Solid LED when ready */
            led_set(true);

            /* Check for motor start */
            if (check_motor_start()) {
                g_state = STATE_BOOSTING;
                state_entry_time = now;
                boost_duty = PWM_PERIOD / 2;  /* Start at 50% duty */

                /* Disable charging during boost */
                charge_enable_pos(false);
                charge_enable_neg(false);
            }
            break;

        case STATE_BOOSTING:
            /* Active discharge assist */
            /* Apply PWM based on AC phase */
            if (g_zc_flag) {
                g_zc_flag = false;

                /* Ramp up PWM over first few cycles */
                if (boost_duty < PWM_PERIOD * 8 / 10) {
                    boost_duty += PWM_PERIOD / 20;
                }
            }

            /* Apply appropriate PWM based on polarity */
            if (g_zc_polarity) {
                pwm_set_pos(boost_duty);
                pwm_set_neg(0);
            } else {
                pwm_set_pos(0);
                pwm_set_neg(boost_duty);
            }

            /* Fast LED blink during boost */
            led_set((now / 50) & 1);

            /* Check if boost duration exceeded */
            if ((now - state_entry_time) > BOOST_DURATION_MS) {
                g_state = STATE_COOLDOWN;
                state_entry_time = now;
                pwm_disable();
            }

            /* Check if motor has started (current dropped) */
            if (!check_motor_start() && (now - state_entry_time) > STARTUP_DETECT_MS) {
                g_state = STATE_COOLDOWN;
                state_entry_time = now;
                pwm_disable();
            }
            break;

        case STATE_COOLDOWN:
            /* Brief cooldown before returning to charging */
            pwm_disable();
            led_set(false);

            if ((now - state_entry_time) > 1000) {
                g_state = STATE_CHARGING;
                state_entry_time = now;
            }
            break;

        case STATE_FAULT:
            /* All outputs disabled, fast LED blink */
            pwm_disable();
            charge_enable_pos(false);
            charge_enable_neg(false);

            /* Blink pattern indicates fault code */
            led_set(((now / 200) % (g_fault + 1)) == 0);
            break;

        case STATE_IDLE:
        default:
            /* Idle state - outputs disabled, waiting */
            pwm_disable();
            charge_enable_pos(false);
            charge_enable_neg(false);
            led_set(false);
            break;
    }
}

/*
 * Main entry point
 */
int main(void) {
    /* Initialize peripherals */
    system_init();
    gpio_init();
    adc_init();
    timer_init();
    exti_init();
    systick_init();

    /* Main loop */
    while (1) {
        state_machine_run();

        /* Small delay to limit loop rate */
        delay_ms(1);
    }

    return 0;
}

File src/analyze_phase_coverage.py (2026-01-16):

#!/usr/bin/env python3
"""
Analyze how our PWM injection interacts with motor inductive load.

Key insight: Inductive loads have lagging current. For a motor at locked rotor:
- Power factor ~0.35 means current lags voltage by ~70°
- Peak current occurs well after peak voltage
- When V_ac is near zero, motor is drawing maximum current

This is actually FAVORABLE for our design because:
- We inject current when V_ac < V_stacked (81.6V)
- This corresponds to the part of the cycle where motor current is highest
- We're supplementing exactly when the generator struggles most
"""

import numpy as np
import matplotlib.pyplot as plt


def analyze_phase_coverage():
    """Analyze when our injection occurs vs when motor needs current."""

    # AC waveform parameters
    V_peak = 170  # Peak voltage
    freq = 60     # Hz
    omega = 2 * np.pi * freq

    # Our design parameters
    V_stacked = 81.6  # Our stacked voltage
    I_inject = 40     # Our max injection current

    # Motor parameters at locked rotor
    motor_pf = 0.35       # Power factor (very lagging)
    motor_lra = 33        # Locked rotor amps (8000 BTU)
    phase_lag = np.arccos(motor_pf)  # ~70 degrees

    # Time array (one cycle)
    t = np.linspace(0, 1/freq, 1000)

    # AC voltage waveform
    v_ac = V_peak * np.sin(omega * t)

    # Motor current waveform (lagging by phase_lag)
    i_motor = motor_lra * np.sqrt(2) * np.sin(omega * t - phase_lag)

    # When can we inject? When |V_ac| < V_stacked
    can_inject = np.abs(v_ac) < V_stacked

    # Our injection current (synchronized to AC polarity)
    # We inject in the same direction as V_ac (positive when V_ac positive)
    i_inject = np.where(can_inject, I_inject * np.sign(v_ac), 0)

    # Actually, we should modulate to follow motor current phase
    # For now, let's see the overlap

    # Calculate what fraction of motor current demand we cover
    # When we inject, how much of the motor's current are we supplying?
    motor_current_during_injection = i_motor[can_inject]
    avg_motor_current_during_injection = np.mean(np.abs(motor_current_during_injection))

    # Coverage fraction (how much of cycle we cover)
    coverage = np.sum(can_inject) / len(can_inject)

    print("=" * 80)
    print("PHASE COVERAGE ANALYSIS")
    print("=" * 80)

    print(f"\nAC waveform: {V_peak}V peak, 60Hz")
    print(f"Our stacked voltage: {V_stacked}V")
    print(f"Coverage: {coverage*100:.1f}% of AC cycle")

    print(f"\nMotor (8000 BTU at locked rotor):")
    print(f"  LRA: {motor_lra}A RMS, {motor_lra * np.sqrt(2):.1f}A peak")
    print(f"  Power factor: {motor_pf} (phase lag: {np.degrees(phase_lag):.0f}°)")

    print(f"\nCritical insight:")
    print(f"  Motor current during our injection window:")
    print(f"    Average: {avg_motor_current_during_injection:.1f}A")
    print(f"    This is {avg_motor_current_during_injection/motor_lra*100:.0f}% of RMS current")

    # The motor draws more current near zero crossing due to phase lag
    # Let's check this
    # At zero crossing (V_ac = 0), motor current is at:
    #   sin(-phase_lag) ≈ sin(-70°) ≈ -0.94 of peak
    # So motor is drawing ~94% of peak current at zero crossing!

    v_ac_zero_crossings = np.where(np.diff(np.sign(v_ac)))[0]
    motor_at_zc = np.mean(np.abs(i_motor[v_ac_zero_crossings]))

    print(f"\nAt voltage zero-crossing:")
    print(f"  Motor current: {motor_at_zc:.1f}A (vs {motor_lra*np.sqrt(2):.1f}A peak)")
    print(f"  This is {motor_at_zc/(motor_lra*np.sqrt(2))*100:.0f}% of peak current!")

    print(f"\n*** This is GOOD for us! ***")
    print(f"  We inject when V_ac < {V_stacked}V")
    print(f"  Motor draws maximum current near V_ac = 0")
    print(f"  Our injection timing aligns with motor's peak current demand!")

    return {
        't': t * 1000,  # Convert to ms
        'v_ac': v_ac,
        'i_motor': i_motor,
        'i_inject': i_inject,
        'can_inject': can_inject,
        'coverage': coverage,
    }


def plot_phase_analysis(data, save_path=None):
    """Plot the phase relationship."""

    fig, axes = plt.subplots(3, 1, figsize=(12, 10))
    fig.suptitle('Phase Analysis: Motor Current vs Our Injection Window',
                 fontsize=14, fontweight='bold')

    t = data['t']
    v_ac = data['v_ac']
    i_motor = data['i_motor']
    can_inject = data['can_inject']

    V_stacked = 81.6

    # Plot 1: AC voltage with injection window
    ax1 = axes[0]
    ax1.plot(t, v_ac, 'b-', linewidth=2, label='V_ac')
    ax1.axhline(y=V_stacked, color='g', linestyle='--', label=f'+{V_stacked}V threshold')
    ax1.axhline(y=-V_stacked, color='g', linestyle='--', label=f'-{V_stacked}V threshold')
    ax1.fill_between(t, -200, 200, where=can_inject, alpha=0.2, color='green',
                     label='Injection window')
    ax1.set_ylabel('Voltage (V)')
    ax1.set_title('AC Voltage and Injection Window')
    ax1.legend(loc='upper right')
    ax1.grid(True, alpha=0.3)
    ax1.set_xlim(0, t[-1])
    ax1.set_ylim(-200, 200)

    # Plot 2: Motor current
    ax2 = axes[1]
    ax2.plot(t, i_motor, 'r-', linewidth=2, label='Motor current (lags 70°)')
    ax2.fill_between(t, -60, 60, where=can_inject, alpha=0.2, color='green')
    ax2.axhline(y=40, color='orange', linestyle=':', label='Our max injection (40A)')
    ax2.axhline(y=-40, color='orange', linestyle=':')
    ax2.set_ylabel('Current (A)')
    ax2.set_title('Motor Current (Lagging Due to Inductance)')
    ax2.legend(loc='upper right')
    ax2.grid(True, alpha=0.3)
    ax2.set_xlim(0, t[-1])
    ax2.set_ylim(-60, 60)

    # Plot 3: Overlay showing alignment
    ax3 = axes[2]
    ax3.plot(t, v_ac / 170 * 40, 'b-', linewidth=1, alpha=0.5, label='V_ac (normalized)')
    ax3.plot(t, i_motor, 'r-', linewidth=2, label='Motor current')
    ax3.fill_between(t, 0, np.abs(i_motor), where=can_inject, alpha=0.3, color='green',
                     label='Current during our injection')
    ax3.set_xlabel('Time (ms)')
    ax3.set_ylabel('Current (A)')
    ax3.set_title('Motor Current During Our Injection Window (shaded)')
    ax3.legend(loc='upper right')
    ax3.grid(True, alpha=0.3)
    ax3.set_xlim(0, t[-1])

    plt.tight_layout()

    if save_path:
        plt.savefig(save_path, dpi=150, bbox_inches='tight')
        print(f"Saved: {save_path}")

    return fig
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

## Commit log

2026-01-16 Add generator soft-start design with supercap-only architecture
    Design evolution:
    - Explored hybrid supercap + electrolytic stacking designs
    - Analyzed motor startup requirements for window AC units
    - Discovered phase alignment advantage for inductive loads
    - Settled on simpler supercap-only design for cost/complexity
    Final design (60 × Tecate 12F 2.7V @ $0.91):
    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
2026-01-16 Reorganize repo: focused README, docs/ for design history
    - New README focuses on the actual build (60× 12F supercaps + STM32)
    - Move design evolution and analysis to docs/
    - Add docs/README.md to navigate historical analysis
    - Keep hardware/design_spec.md as the authoritative spec
2026-01-16 Replace design_spec.md with project.kct (kicad-tools format)
    The .kct format provides structured project specification including:
    - Project metadata and intent
    - Electrical/mechanical requirements
    - Component suggestions with rationale
    - Design decisions with alternatives considered
    - Progress tracking with phase checklists
    - BOM summary
2026-01-16 Add KiCad schematic and STM32G031 firmware
    - Generate schematic with 97 components via Python script
    - Complete firmware with state machine for supercap charge/discharge
    - Zero-crossing detection, PWM control, ADC sensing, safety protection
    - Makefile, linker script, and flash programming tools
    [softstart.kicad_sch]
2026-01-16 Add PCB layout generator with 4-layer compact option
    - generate_pcb.py: Creates initial PCB from schematic
    - Supports 2-layer (200x120mm) and 4-layer compact (160x100mm)
    - Groups components by function for logical placement
    - 4-layer stackup: F.Cu/GND/PWR/B.Cu for high current
    Note: Generated PCB needs footprint import via KiCad
    "Update PCB from Schematic" to pass DRC.
    [softstart.kicad_pcb]
2026-01-17 Fix ERC violations in schematic generator
    Reduce ERC errors from 271 to 6 (5 intentional design choices):
    - Fix bridge rectifier pin references (use pin numbers not names)
    - Fix T-junction wiring by breaking vertical buses into segments
    - Add no-connect flags for unused MCU pins (PC15, PB9/PC14)
    - Wire gate driver IN- pins to GND and connect OUTL parallel to OUTH
    - Fix 4-terminal Kelvin shunt resistor wiring
    - Add PWR_FLAG on GND rail for proper power annotation
    - Move bypass cap GND bus left to avoid crossing MCU signal wires
    Remaining errors are intentional: L7812→LDO cascade, gate driver
    parallel outputs (OUTH/OUTL).
    [softstart.kicad_pcb, softstart.kicad_sch]
2026-01-17 Fix MCU debug signal routing to avoid AC wire crossings
    - Route SWDIO, SWCLK, NRST directly from MCU to SWD connector
    - Use direct wires instead of labels to avoid horizontal crossings
    - Route right-side (toward SWD connector) to avoid AC section
    - Move SWD connector to Y=MCU_Y+10 to avoid 3.3V GND rail
    - Use individual power symbols per bypass cap (no shared vertical bus)
    Still investigating: ZC_OUT/AC_L crossing, PA13/PWR connection
2026-01-17 Convert MCU signals to global labels to reduce wire crossings
    Use global labels instead of long horizontal wires for:
    - PRECHG_POS, PRECHG_NEG (precharge control)
    - LED_STATUS (status LED control)
    - Relocated ZC pull-up resistor and adjusted VCC routing
    Reduces ERC wire crossing issues by connecting signals by name
    instead of through physical wire routes across the schematic.
    Note: Some wire crossing warnings remain in ZC circuit area -
    may require manual adjustment in KiCad if needed.
    [softstart.kicad_sch]
2026-01-17 Fix AC_L wire crossings with ZC_OUT and SWD signals
    - Move ZC pull-up resistor directly above H11AA1 output pin to minimize horizontal routing
    - Move SWD connector (J3) up and right to avoid SC_POS_Y (85mm) conflicts
    - Replace physical SWD wiring with global labels to eliminate wire crossings
    - Simplify ZC output wiring path
    ERC now shows 11 violations (6 errors, 5 warnings) - all expected:
    - 6 errors: power output connections, half-bridge driver outputs
    - 5 warnings: lib mismatches, expected supercap series connections
    [softstart.kicad_sch]
2026-01-17 Add routed PCB and gitignore fp-info-cache
    [softstart_routed.kicad_pcb]
2026-01-17 Add PWR_FLAG on +3.3V rail to fix power_pin_not_driven ERC error
    The distributed +3.3V power symbols need a PWR_FLAG to indicate the
    net is driven by the AMS1117 regulator output.
    [softstart.kicad_sch]
2026-01-17 Fix ERC pin_to_pin errors in schematic generator
    - Renumber gate drivers U6,U7 to U9,U10 to fix duplicate references
    (U6 was H11AA1, U7 was L7812)
    - Replace OUTL parallel wiring with no-connect flags on all gate drivers
    (using OUTH only for gate drive eliminates Output-to-Output errors)
    - Route MCU VDD wire at lower Y level to avoid crossing +12V output rail
    (prevents L7812 OUT from shorting to AMS1117 VO)
    [softstart.kicad_sch]
2026-01-18 Add +3.3V power symbol on AMS1117 output to fix isolated net ERC error
    The +3.3V power symbols on bypass caps were on an isolated net not
    connected to the AMS1117-3.3 regulator output. Added a +3.3V power
    symbol on the output rail to connect them globally.
    ERC now passes with 0 errors (2 expected warnings for series junction).
    [softstart.kicad_sch]
2026-01-19 Add routed PCB and manufacturing files
    Generated using kicad-tools with C++ router backend:
    - 136 footprints placed (132 from schematic + 4 mounting holes)
    - 34/39 nets routed (87%)
    - 30,721 segments, 124 vias
    - 3,371mm total trace length
    - DRC: 0 violations
    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
    [softstart-B_Courtyard.gbr, softstart-B_Cu.gbl, softstart-B_Fab.gbr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]
2026-01-19 Increase C8 bulk capacitor from 100uF to 1000uF 25V
    Address power supply review concerns:
    - 100uF was insufficient smoothing after bridge rectifier
    - Ripple was ~8.3V at 100mA, marginal headroom for LM7812
    - Now 1000uF reduces ripple to ~0.83V, stable regulation
    Changed footprint from 1206 SMD to 10mm radial electrolytic.
    Updated PCB placement to accommodate larger component.
    [softstart.kicad_sch]
2026-01-19 Update routed PCB and manufacturing files
    Regenerated with routing failure reporting and float precision fixes.
    34/39 nets routed (5 blocked by off-grid pad positions - see #956).
    [softstart-B_Courtyard.gbr, softstart-B_Cu.gbl, softstart-B_Fab.gbr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]
2026-01-19 Regenerate PCB routing with updated C8 (1000uF) placement
    Routed 34/39 nets using kicad-tools C++ router:
    - 30,719 segments, 124 vias
    - 3,373.5mm total trace length
    5 nets remain unrouted due to off-grid pad positions
    (tracked in kicad-tools issues #956, #957)
    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
2026-01-19 Add SPICE simulation infrastructure for MCU supply stability analysis
    Three simulation test benches to validate power supply behavior:
    1. startup_transient.cir - Power-on with discharged supercaps
    - Models charging current impact on rectified voltage
    - Verifies MCU supply stays above brown-out threshold
    2. droop_event.cir - Generator voltage droop scenario
    - Simulates 25% voltage sag triggering supercap assist
    - Verifies no MCU reset during transition
    3. brownout_threshold.cir - Minimum operating voltage
    - Slow voltage ramp to find regulation limits
    - Calculates safety margins from nominal 120V
    Component models in lib/components.lib:
    - LM7812/AMS1117 with dropout behavi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
2026-01-19 Add working MCU supply stability simulations
    Two new reliable simulation test benches:
    1. mcu_supply_simple.cir - Normal operation test
    - Verifies supply at 120V RMS nominal
    - Results: Rectified 159-168V, 12V/3.3V stable
    2. mcu_supply_lowvoltage.cir - Low voltage margin test
    - Tests at 60V RMS (50% voltage)
    - Results: Still stable with 67V headroom!
    Voltage margin analysis:
    - MCU supply stable down to ~11V RMS (9% of nominal)
    - At 11V RMS, rectified voltage (14.5V) just reaches LM7812 dropout
    - Design has 91% voltage margin before MCU brownout
    The 1000uF bulk capacitor (C8) provides excellent filtering
    and the cascaded regulators maintain stable 3.3V output
    even under severe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
2026-01-20 Replace discrete 12V supply with HLK-PM12 AC-DC module
    - Remove D5 (MB6S bridge rectifier), C8 (bulk cap), U7 (LM7812)
    - Add PS1 (HLK-PM12) isolated AC-DC module for 12V rail
    - Update generate_pcb_v4.py placements for new power supply
    - Regenerate PCB (29/39 nets routed, PS1 footprint pending)
    The discrete supply components couldn't handle 170V rectified mains:
    - C8 was rated 25V (would fail immediately)
    - LM7812 max input is 35V (would be destroyed)
    HLK-PM12 provides safe, isolated 12V from AC mains directly.
    [softstart.kicad_sch]
